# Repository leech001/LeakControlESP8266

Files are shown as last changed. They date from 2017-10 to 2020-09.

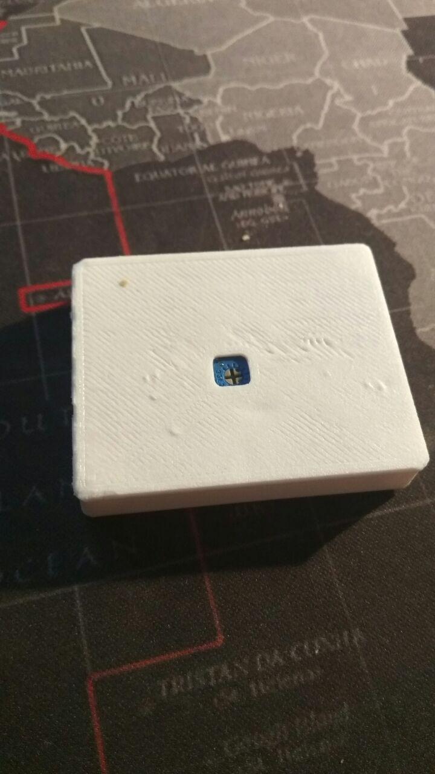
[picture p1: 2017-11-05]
img/photo_2017-11-05_14-51-28.jpg

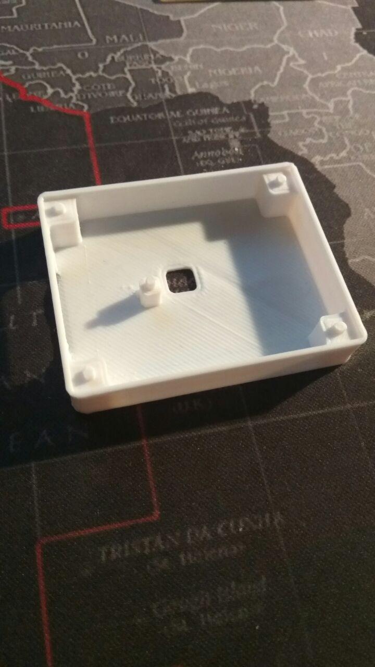
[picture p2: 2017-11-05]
img/photo_2017-11-05_14-51-31.jpg

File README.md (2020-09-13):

# This repository is archive. New version on https://github.com/leech001/LeakControl

# Система контроля утечек воды (Leak Control) на базе ESP8266 (NodeMCU)

Простейшая система по контролю утечек (протечек) в местах водаразбора.

## Создается на основе следующих компонентов:
1. NodeMCU https://ru.aliexpress.com/item/New-Wireless-module-NodeMcu-Lua-WIFI-Internet-of-Things-development-board-based-ESP8266-with-pcb-Antenna/32453920794.html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
2. MotorShield https://ru.aliexpress.com/item/Free-shipping-NodeMCU-Motor-Shield-Board-L293D-for-ESP-12E-from-ESP8266-esp-12E-kit-diy/32390158973.html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
3. OrangePI https://ru.aliexpress.com/item/Orange-Pi-PC-Plus-SET5-Orange-Pi-PC-Plus-Transparent-ABS-Case-Power-Supply-Development-Board/32669760149.html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
4. Блок питания для кранов https://ru.aliexpress.com/item/12V2A-AC-100V-240V-Power-Adapter-Converter-Power-Supply-3528-5050-LED-strip-power-EU-UK/32739387151.html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
5. Преобразователь напряжения https://ru.aliexpress.com/item/5pcs-lot-Max-DC-DC-XL4005-Step-5A-Down-Adjustable-Power-Supply-Module-LED-Lithium-Charger/32750014775.html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
6. Шаровый кран https://ru.aliexpress.com/item/Free-Shipping-Motorized-ball-valve-DN15-2-way-electrical-valve/1000001800120.html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
7. Датчик утечки https://ru.aliexpress.com/item/Smart-Electronics-For-Arduino-Diy-Starter-Kit-3-3-5V-Raindrops-Rain-Weather-Humidity-Sensitive-Detection/32460014764.html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

## Принцип работы
Датчики утечки раскладываются в местах возможных утечек. В случае намокания элемента и поступления сигнала на ножку NodeMCU отрабатывает скрипт и на краны автоматически поступает сигнал на закрытие.
Так же формируется событие через MQTT, что произошла утечка и через скрипт wbot.py данное уведомление направляется в соответствующую группу в Telegram через Telegram Bot.
Управление кранами также доступно через специальную клавиатуру управления Telegram Bot.

## Подключение
1. Подключение кранов и датчика утечки к NodeMCU Motor Shield 
NodeMCU

## Установка
1. На OrangePI или аналоги устаннавливается MQTT Broker (mosquito) который слушает события и Telegram бот для управления.

    1.1. Используя Docker Compose
    * Обновляем прошивку до версии ядра Linux не ниже 4.х (Мainline kernel) https://www.armbian.com/orange-pi-pc-plus/
    * Устанавливаем Docker c учетом архитектуры **armhf** (https://docs.docker.com/install/linux/docker-ce/ubuntu/#set-up-the-repository)
    * Устанавливаем Docker Compose `pip install docker-compose`
    * Запускаем `sudo docker-compose up -d ` в директории с `docker-compose.yml`
    
    1.2. В ручную
    * Обновляем пакеты `sudo apt-get update`
    * Устанавливаем MQTT Broker Mosquitto (http://mosquitto.org/) `apt-get install mosquitto`
    * Устанавливаем telepot  `pip3 install telepot`
    * Устанавливаем paho.mqtt `pip3 install paho-mqtt`
    * Запускаем Python скрипт для уведомлений и управления посредством Telegram бота (Telepot) `python3 ./telegrambot.py`
2. Заливается в плату NodeMCU прошивка MicroPython http://micropython.org/download#esp8266
3. На плату NodeMCU записываются скрипты из папки ESP8266

## Настройка
1. Настройка NodeMCU `\src\esp8266\config.py` (настройка управлющих пинов и MQTT)
2. Настройка Telegram Bot `\src\OrangePI\telegram_bot\app-files\telegrambot.py` (BOT API TOKEN и MQTT)

# Control system of water leaks (Leak Control) based on ESP8266 (NodeMCU)
The simplest system to control leaks (leaks) watersmore.

Leak sensors are put in places of possible leaks. In the case of the wet element and the signal on the leg ESP8266 to work out the script and on the valves automatically receive a signal to close. The same event is generated via MQTT that has leaked through the script wbot.py this notice is sent to the appropriate group Telegram via Telegram Bot. The crane is also available via special keyboard control Telegram Bot.

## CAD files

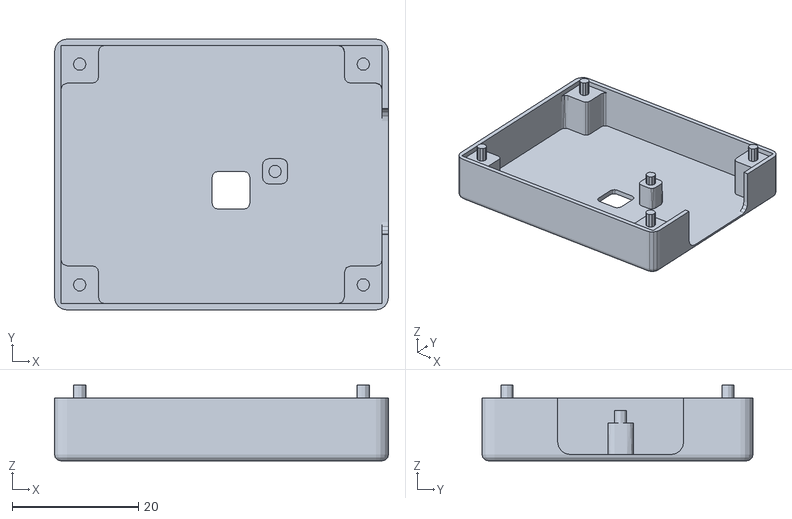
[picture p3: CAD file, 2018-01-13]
3D_models/sensor_l_01.stl
53.0 x 43.0 x 12.0

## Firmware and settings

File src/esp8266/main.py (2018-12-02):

import gc
import uasyncio as asyncio
import wifi
import machine
import utime as time
import usocket as socket
import ustruct as struct
from umqtt.simple import MQTTClient
from machine import WDT
import config

wdt = WDT()
gc.enable()
wifi.activate()
int_err_count = 0
ping_mqtt = 0
ping_fail = 0
water = False

place_topic = config.CONFIG['DEVICE_PLACE'] + "/"\
              + config.CONFIG['DEVICE_TYPE'] + "/"\
              + config.CONFIG['DEVICE_PLACE_TYPE'] + "/"\
              + config.CONFIG['DEVICE_PLACE_NAME'] + "/"

device_topic = config.CONFIG['DEVICE_PLACE'] + "/"\
               + config.CONFIG['DEVICE_TYPE'] + "/"\
               + config.CONFIG['DEVICE_PLACE_TYPE'] + "/"\
               + config.CONFIG['DEVICE_PLACE_NAME'] + "/"\
               + config.CONFIG['DEVICE_ID'] + "/"


def time_now():
    ntp_query = bytearray(48)
    ntp_query[0] = 0x1b
    try:
        addr = socket.getaddrinfo(config.host, 123)[0][-1]
        s = socket.socket(socket.AF_INET, socket.SOCK_DGRAM)
        s.settimeout(1)
        s.sendto(ntp_query, addr)
        msg = s.recv(48)
        s.close()
        val = struct.unpack("!I", msg[40:44])[0]
        return val - config.ntp_delta
    except Exception as error:
        print("Error: [Exception] %s: %s" % (type(error).__name__, error))
        time.sleep(60)
        machine.reset()


def settime():
    try:
        t = time_now()
        tm = time.localtime(t)
        tm = tm[0:3] + (0,) + tm[3:6] + (0,)
        machine.RTC().datetime(tm)
    except Exception as error:
        print("Error: [Exception] %s: %s" % (type(error).__name__, error))
        time.sleep(60)
        machine.reset()


settime()


# Check Internet connection
def internet_connected(host='8.8.8.8', port=53):
    global int_err_count
    while True:
        s = socket.socket(socket.AF_INET, socket.SOCK_STREAM)
        s.settimeout(1.0)
        try:
            s.connect((host, port))
            int_err_count = 0
            return True
        except Exception as error:
            print("Error Internet connect: [Exception] %s: %s" % (type(error).__name__, error))
            return False
        finally:
            s.close()


# Check sensor
async def check_sensor():
    global water
    while True:
        await asyncio.sleep(1)
        print("Check sensor ...")
        if (config.ws.check() == 0) and (water is False):
            print("Water on floor!")
            water = True
            config.tap_cold.close()
            config.tap_hot.close()
            client.publish(device_topic + "data/water", "yes")

        if config.ws.check() != 0:
            print("Not leaking!")
            client.publish(device_topic + "data/water", "no")
            water = False


async def tap_check():
    while True:
        await asyncio.sleep(1)
        if config.tap_cold.tap_state == "open":
            await config.tap_cold.open()

        if config.tap_cold.tap_state == "close":
            await config.tap_cold.close()

        if config.tap_hot.tap_state == "open":
            await config.tap_hot.open()

        if config.tap_hot.tap_state == "close":
            await config.tap_hot.close()


def on_message(topic, msg):
    global ping_fail
    print("Topic: %s, Message: %s" % (topic, msg))

    if config.CONFIG['DEVICE_ID'] + "/state/check/mqtt" in topic:
        if int(msg) == ping_mqtt:
            print("MQTT pong true...")
            ping_fail = 0
        else:
            print("MQTT pong false... (%i)" % ping_fail)

    if "/state/ping" in topic:
        send_mqtt_pong(msg)

    if "/tap/cold" in topic:
        if msg == b"close":
            config.tap_cold.tap_state = "close"
        if msg == b"open":
            config.tap_cold.tap_state = "open"

    if "/tap/hot" in topic:
        if msg == b"close":
            config.tap_hot.tap_state = "close"
        if msg == b"open":
            config.tap_hot.tap_state = "open"

    if "/data/water" in topic:
        if msg == b"yes":
            config.tap_cold.tap_state = "close"
            config.tap_hot.tap_state = "close"


# Pong MQTT connect
def send_mqtt_pong(pong_msg):
    print(pong_msg.decode("utf-8"))
    client.publish(device_topic + "state/pong",
                   pong_msg.decode("utf-8"))


# Check MQTT brocker
async def mqtt_check():
    global ping_fail
    global ping_mqtt
    while True:
        await asyncio.sleep(10)
        ping_mqtt = time.time()
        client.publish(device_topic + "state/check/mqtt", "%s" % ping_mqtt)
        print("Send MQTT ping (%i)" % ping_mqtt)
        ping_fail += 1

        if ping_fail >= config.CONFIG['MQTT_CRIT_ERR']:
            print("MQTT ping false... reset (%i)" % ping_fail)
            machine.reset()

        if ping_fail >= config.CONFIG['MQTT_MAX_ERR']:
            print("MQTT ping false... reconnect (%i)" % ping_fail)
            client.disconnect()
            mqtt_reconnect()


# MQTT reconnect
def mqtt_reconnect():
    global client
    try:
        client = MQTTClient(config.CONFIG['MQTT_CLIENT_ID'], config.CONFIG['MQTT_BROKER'],
                            user=config.CONFIG['MQTT_USER'],
                            password=config.CONFIG['MQTT_PASSWORD'], port=config.CONFIG['MQTT_PORT'])
#        client.DEBUG = True
        client.set_callback(on_message)
        client.connect(clean_session=True)
        client.subscribe(place_topic + "#")
        print("ESP8266 is Connected to %s and subscribed to %s topic" % (
                config.CONFIG['MQTT_BROKER'], place_topic + "#"))

        client.publish(device_topic + "info", "%s" % [config.CONFIG['DEVICE_PLACE'], config.CONFIG['DEVICE_TYPE'],
                                                      config.CONFIG['DEVICE_PLACE'], config.CONFIG['DEVICE_PLACE_NAME'],
                                                      config.CONFIG['DEVICE_ID']])
    except Exception as error:
        print("Error in MQTT reconnection: [Exception] %s: %s" % (type(error).__name__, error))


# Check MQTT message
async def check_message():
    while True:
        await asyncio.sleep(1)
        print("Check message...")
        try:
            client.check_msg()
        except Exception as error:
            print("Error in mqtt check message: [Exception] %s: %s" % (type(error).__name__, error))
            mqtt_reconnect()
        wdt.feed()


# Check Internet connected and reconnect
async def check_internet():
    global int_err_count
    try:
        while True:
            await asyncio.sleep(60)
            print("Check Internet connect... ")
            if not internet_connected():
                print("Internet connect fail...")
                int_err_count += 1

                if int_err_count >= config.CONFIG['INT_CRIT_ERR']:
                    client.disconnect()
                    wifi.wlan.disconnect()
                    machine.reset()

                if int_err_count >= config.CONFIG['INT_MAX_ERR']:
                    print("Internet reconnect")
                    client.disconnect()
                    wifi.wlan.disconnect()
                    wifi.activate()
    except Exception as error:
        print("Error in Internet connection: [Exception] %s: %s" % (type(error).__name__, error))


mqtt_reconnect()
try:
    loop = asyncio.get_event_loop()
    loop.create_task(check_sensor())
    loop.create_task(check_message())
    loop.create_task(check_internet())
    loop.create_task(mqtt_check())
    loop.create_task(tap_check())
    loop.run_forever()
except Exception as e:
    print("Error: [Exception] %s: %s" % (type(e).__name__, e))
    time.sleep(60)
    machine.reset()

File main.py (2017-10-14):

# import sys
# import os
import esp
import wifi
import time
import gc
from umqtt.robust import MQTTClient
# from machine import Pin
# from machine import Timer
from wsensor import WS
from tap import Tap

esp.osdebug(0)
gc.enable()

wifi.activate()

TOPIC_PREFIX = b"bath/small/"

tap_cold = Tap(2)
tap_hot = Tap(1)
ws = (WS(16), WS(5), WS(4), WS(0), WS(2))   # Water sensor tuples (pin)


def check_sensor():
    for item in ws:
        if item.check() == 0:
            print("Water on floor!")
            client.publish(TOPIC_PREFIX + b"water/", "yes")
            tap_cold.close()
            tap_hot.close()


def sub_cb(topic, msg):
    print(topic, msg)
    s_topic = str(topic).split("/")

    if s_topic[2] == "tap":
        if s_topic[3] == "cold":
            if msg == b"close":
                print(tap_cold.close())
            if msg == b"open":
                print(tap_cold.open())
        elif s_topic[3] == "hot":
            if msg == b"close":
                print(tap_hot.close())
            if msg == b"open":
                print(tap_hot.open())


client = MQTTClient("ESPython", "192.168.0.21", port=1883, user="user", password="private")
# client = MQTTClient("ESPython", "broker.mqttdashboard.com", port=8000)
client.DEBUG = True
client.set_callback(sub_cb)
client.connect()
client.subscribe(TOPIC_PREFIX + b"#")


# tim = Timer(-1)
# tim.init(period=10000, mode=Timer.PERIODIC, callback=lambda t:reconnect())


while True:
    check_sensor()
    client.check_msg()
    time.sleep(1)

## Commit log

2017-11-05 Correct code
    [sensor_l_01.stl]
2018-01-13 Add check Internet and MQTT connection
    [sensor_l_01.stl]
2018-11-18 Correct bugs and add WDT
    [config.py, main.py, tap.py]
2018-12-02 Minor change
    Add auto reconnect if error on check mqtt message
    [config.py, main.py]
